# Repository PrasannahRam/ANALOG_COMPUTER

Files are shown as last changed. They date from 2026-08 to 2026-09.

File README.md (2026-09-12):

# ±15V Regulated Power Supply — Design Documentation

Part of the analog computer project (adder, subtractor, multiplier, integrator, differentiator built around NE5532D op-amps). This document covers the power supply subsystem: design goals, component selection, calculations, and simulation results.

## 1. Purpose

Provide a stable, low-noise ±15V DC supply to power the op-amp circuits and the CD4051 switching stage. Op-amps are sensitive to supply noise (it couples directly into the signal path), so filtering and regulation are prioritized alongside basic voltage accuracy.

## 2. Design Specifications

| Parameter | Value |
|---|---|
| Regulated output | +15V and −15V DC |
| Mains input | 230V RMS, 50Hz (Sri Lanka standard) |
| Regulator ICs | LM7815CT (positive), LM7915CT (negative) |
| Ripple target | As low as practical (achieved: sub-mV on final output, see §7) |

## 3. Circuit Architecture

```
Mains (230V, 50Hz)
      │
Center-tapped step-down transformer (230V primary : 15V-0-15V secondary)
      │
Full-wave rectifier (4× 1N4007, dual-rail configuration)
      │  (+ snubber caps across each diode)
Main filter capacitors (C1, C2 — bulk smoothing)
      │
Linear regulators (LM7815CT / LM7915CT)
      │  (+ input stability caps, output smoothing + HF caps)
Regulated ±15V output → op-amp circuit boards
```

The transformer's center tap is the single system ground reference (star ground) that all other grounds in the analog computer tie back to.

## 4. Component List (Bill of Materials)

| Ref. Des. | Component | Value / Part | Qty | Purpose |
|---|---|---|---|---|
| T1 | Center-tapped step-down transformer | 230V : 15V-0-15V | 1 | Steps mains down to a safe, rectifiable secondary voltage |
| D1–D4 | Rectifier diode | 1N4007 (1A, 1000V) | 4 | Full-wave rectification of both secondary halves into + and − rails |
| CSNUB1–CSNUB4 | Ceramic capacitor | 100nF | 4 | Suppress diode switching (reverse-recovery) noise |
| C1, C2 | Electrolytic capacitor | 2200µF, ≥35V | 2 | Main bulk ripple filtering after rectification |
| C3, C4 | Ceramic capacitor | 330nF | 2 | Regulator input stability (per datasheet) |
| U1 | Negative voltage regulator | LM7915CT | 1 | Regulates negative rail to −15V |
| U2 | Positive voltage regulator | LM7815CT | 1 | Regulates positive rail to +15V |
| C5, C6 | Electrolytic capacitor | 100µF | 2 | Regulator output bulk smoothing, transient response |
| C7, C8 | Ceramic capacitor | 100nF | 2 | High-frequency noise cleanup on regulated output |
| RL1, RL2 | Load resistor (simulation only) | 300Ω | 2 | Represents op-amp board current draw during simulation — not a real PCB part |
| F1 | Fuse (mains side) | Size per transformer VA rating | 1 | Safety — not simulated, required for physical build |

## 5. Principal Calculations

### 5.1 Transformer secondary voltage / turns ratio

The LM7815/LM7915 regulators need a minimum input voltage roughly 2–2.5V above their 15V output (dropout voltage), with a recommended practical minimum of about **17.5V** to regulate reliably.

Target secondary: **15V RMS per half** (30V RMS across the full secondary winding, tip to tip, since Multisim's turns-ratio field refers to the whole winding, not one half of a center-tapped winding).

```
Turns ratio = V_primary / V_secondary_full
            = 230V / 30V
            ≈ 7.65
```

This matches the corrected ratio used in simulation (previously set to ~15.3, which halved the intended per-side voltage — corrected to ~7.65 to get 15V RMS per half, confirmed in simulation).

### 5.2 Peak and rectified voltage

```
V_peak (per secondary half) = V_rms × √2
                             = 15V × 1.414
                             ≈ 21.2V

V_rectified ≈ V_peak − V_diode_drop
            ≈ 21.2V − 0.9V (typical 1N4007 forward drop)
            ≈ 20.3V
```

### 5.3 Ripple voltage across main filter caps (C1, C2)

```
V_ripple = I_load / (f_ripple × C)
```

Using an example load of 100mA per rail (**replace with your actual measured/estimated total op-amp + CD4051 current draw**) and C = 2200µF, with ripple frequency 100Hz (double the 50Hz mains, since full-wave rectification):

```
V_ripple = 0.1A / (100Hz × 2200µF)
         = 0.1 / 0.22
         ≈ 0.45V peak-to-peak
```

### 5.4 Regulator headroom check

```
Minimum voltage at ripple valley ≈ V_rectified − V_ripple
                                  ≈ 20.3V − 0.45V
                                  ≈ 19.85V
```

This sits comfortably above the ~17.5V minimum input requirement, giving roughly **2.3V of margin** even at the lowest point of the ripple waveform — this margin is what actually determines real-world stability under load, more so than the average/nominal voltage.

### 5.5 Regulator power dissipation (heatsinking check)

```
P_dissipated = (V_in_avg − V_out) × I_out
             = (20V − 15V) × 0.1A
             = 0.5W
```

At this dissipation level, the LM7815CT/LM7915CT can run without a heatsink, though adding a small clip-on heatsink is inexpensive insurance if the actual current draw ends up higher than the 100mA example used here.

**Note:** All calculations above use an assumed 100mA per rail as a placeholder. Recalculate §5.3–5.5 with your actual total current draw (sum of all NE5532D op-amp supply currents + CD4051 quiescent current) once known, for accurate final numbers.

## 6. Capacitor Placement Reasoning

| Capacitor(s) | Role | Why it's needed |
|---|---|---|
| CSNUB1–4 | Diode snubbers | Absorb reverse-recovery switching spikes from the rectifier diodes at the source, before they propagate as noise |
| C1, C2 | Bulk filtering | Smooth the pulsating rectifier output into near-steady DC before the regulator |
| C3, C4 | Regulator input stability | Prevent the regulator's internal feedback loop from oscillating due to trace/wire inductance |
| C5, C6 | Output bulk smoothing | Handle sudden current demand (e.g. op-amp transients) and mop up residual ripple |
| C7, C8 | Output HF cleanup | Ceramic caps handle high-frequency noise that electrolytics can't filter well, right before the rail reaches the op-amps |

**Overall pattern:** large electrolytics handle bulk/low-frequency smoothing, small ceramics handle high-frequency cleanup and stability, and snubber caps address noise at its source rather than filtering it out afterward.

## 7. Simulation Results (Multisim)

| Node | DC Value | Ripple (p-p) | Ripple Frequency |
|---|---|---|---|
| +15V rail (PR1, regulator output) | +14.9V | 198µV | 100Hz |
| −15V rail (PR2, regulator output) | −14.9V | 1.01mV | 100Hz |
| Secondary winding (PR3, pre-rectification) | — | 41.6V (raw AC) | 50Hz |

The 14.9V vs. 15.0V nominal is within the regulator's normal ±4% tolerance and is not a design issue. The sub-millivolt ripple on both regulated rails confirms the filtering/regulation stage is working as intended — well below what's needed for clean op-amp operation.

## 8. Build and Layout Recommendations

- **Star grounding:** all grounds (transformer center tap, regulator GND pins, op-amp board ground) should meet at a single point rather than daisy-chaining, to avoid ground loops.
- **Low-ESR electrolytics:** use low-ESR rated capacitors for C1, C2, C5, C6 where possible — they filter ripple more effectively and add less of their own high-frequency noise than generic electrolytics of the same value.
- **Physical placement:** keep all capacitors as close as possible to their respective pins (especially C3/C4 at the regulator input, and C7/C8 at the output) — lead/trace length reintroduces the inductance these capacitors are meant to cancel out.
- **Local decoupling at the op-amp boards:** in addition to this supply's own output capacitors, add local decoupling (e.g. ferrite bead + small ceramic/electrolytic pair) right where power enters each op-amp board, to guard against noise picked up along the wiring run.
- **Mains safety (not simulated):** include a fuse sized to the transformer's rated VA, and follow standard mains-wiring safety practice for the primary side.
- **Heatsinking:** add a small heatsink to U1/U2 if actual measured current draw pushes dissipation meaningfully above the ~0.5W estimate in §5.5.

## 9. Assumptions to Verify Before Finalizing PCB

- Actual total current draw of all op-amp stages + CD4051 switching stage (used to refine §5.3–5.5).
- Transformer VA/current rating sized with margin above that total.
- Confirm real 1N4007 forward voltage drop at your actual operating current (datasheet graph, not just the 0.7–0.9V typical figure used here).

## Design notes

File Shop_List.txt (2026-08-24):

RESISTORS — Metal Film

270 Ω       1%   0.25 W    ×3    (R1,R2,R3)
4.7 kΩ      1%   0.25 W    ×1    (R4)
3.3 kΩ      1%   0.25 W    ×1    (R5)
2.2 kΩ      1%   0.25 W    ×1    (R6)
2.2 kΩ      0.1% 0.25 W    ×4    (R7,R8,R9,R10)
50 Ω        1%   0.25 W    ×2    (R11,R12)
100 Ω       1%   0.25 W    ×1    (R13)
10 kΩ       1%   0.25 W    ×3    (R14,R16,R18)
1 kΩ        1%   0.25 W    ×2    (R15,R17)
1 MΩ        1%   0.25 W    ×1    (R20)

CAPACITORS

1 µF        ±5%  50 V+      ×5    (C1,C2,C3,C4,C5)
            Film preferred

OP-AMPS

NE5532                    ×3     (U1,U2,U3)

TRANSISTORS

2N3904                    ×10    (Q1–Q6 + spares)

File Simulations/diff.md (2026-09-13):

# Differentiator

### Triangular Input 
| frequency | C
| --- | --- |
1 - 10khz|100pF
10Hz - 1khz|10nF
5Hz - 10hz|100nF
1Hz - 5hz|1000nF

### Square Input
- Follow the above values.
- If unwanted spikes encountered increase the R2 value. 
- If the wave is distorted, reduce the R2 value.

---
---

# Component Justification for Active Differentiator Circuit

### 1. Active Element
* **Op-Amp (U1B - NE5532P):**
  * **Role:** Core high-speed, low-noise operational amplifier providing the required open-loop gain for differentiation.
  * **Value / Selection:** `NE5532P`
  * **Justification:** An ideal differentiator requires an op-amp with high bandwidth and slew rate to accurately process steep signal slopes ($\frac{dV}{dt}$) without slew-rate limiting or phase distortion. The NE5532 provides a high gain-bandwidth product ($10\text{ MHz}$), low noise voltage ($5\text{ nV}/\sqrt{\text{Hz}}$), and a slew rate of $9\text{ V}/\mu\text{s}$, making it suitable for processing signals up to $10\text{ kHz}$.

---

### 2. Switched Frequency-Band Capacitors ($C1, C2, C4, C5$)
* **Role:** Input differentiation capacitors determining the time constant $\tau = R_f C_{in}$ for each operating band.
* **Justifications:**
  * **$C1 = 1\ \mu\text{F}\ (1000\text{ nF})$ [$1\text{ Hz} - 5\text{ Hz}$]: At very low frequencies, the derivative ($\frac{dV}{dt}$) is tiny. A large capacitance ($1\ \mu\text{F}$) provides enough input current to yield a readable output voltage gain ($0.63\text{ V/V}$ to $3.14\text{ V/V}$) across $R1 = 100\text{ k}\Omega$.
  * **$C5 = 100\text{ nF}$ [$5\text{ Hz} - 10\text{ Hz}$]: Scaled down by $10\times$ relative to $C1$ to offset the higher input frequency range, keeping maximum band gain at $0.63\text{ V/V}$.
  * **$C4 = 10\text{ nF}$ [$10\text{ Hz} - 1\text{ kHz}$]: Covers two decades of frequency. A $10\text{ nF}$ value keeps the gain bounded between $0.063\text{ V/V}$ and $6.28\text{ V/V}$ at $1\text{ kHz}$, preventing op-amp output rail saturation.
  * **$C2 = 150\text{ pF}$ [$10\text{ kHz}$]: At high frequencies, $\frac{dV}{dt}$ is extremely large. Reducing $C_{in}$ to $150\text{ pF}$ maintains a gain near unity ($0.94\text{ V/V}$), preventing high-frequency noise amplification.

---

### 3. Stability & Input Resistance ($R2, R6$)
* **Role:** Input series limiting resistors.
* **Value / Selection:** $R2 = 10\text{ k}\Omega$, $R6 = 1\text{ k}\Omega$
* **Justification:** An ideal differentiator has zero input resistance, causing infinite high-frequency gain and unconditional instability (self-oscillation). Adding input series resistance caps the maximum high-frequency gain to $A_{max} = \frac{R1}{R_{in}}$ and forms a high-pass corner $f_c = \frac{1}{2\pi R_{in} C_{in}}$, stabilizing the feedback loop and dampening high-frequency noise.

---

### 4. Feedback Network ($R1, C6$)
* **Feedback Resistor ($R1 = 100\text{ k}\Omega$):**
  * **Role:** Sets the overall differentiation scaling factor ($V_{out} = -R1 \cdot C_{in} \cdot \frac{dV_{in}}{dt}$).
  * **Justification:** A high resistance ($100\text{ k}\Omega$) yields high transimpedance gain without requiring large, bulky input capacitors, keeping the load current within the NE5532 driving limit.
* **Feedback Capacitor ($C6 = 22\text{ pF}$):**
  * **Role:** High-frequency compensation capacitor (low-pass filter pole).
  * **Justification:** Placed in parallel with $R1$ to create a second-order pole at $f_p = \frac{1}{2\pi R1 C6} \approx 72.3\text{ kHz}$. This rolls off gain beyond the $10\text{ kHz}$ target bandwidth, suppressing high-frequency op-amp noise and ringing.

---

### 5. DC Compensation & Output Coupling ($R3, C3, R4$)
* **Bias Resistor ($R3 = 100\text{ k}\Omega$):**
  * **Role:** Non-inverting terminal DC bias balance.
  * **Justification:** Equalizes the DC source resistance seen by both inverting and non-inverting terminals ($R3 = R1 = 100\text{ k}\Omega$). This cancels out DC offset voltage shifts caused by the NE5532 input bias currents.
* **Output AC Coupling Capacitor ($C3 = 470\ \mu\text{F}$):**
  * **Role:** DC blocking capacitor at the output stage.
  * **Justification:** Prevents any residual op-amp DC offset voltage from reaching the measurement load/oscilloscope.
* **Output Load Resistor ($R4 = 100\text{ k}\Omega$):**
  * **Role:** Output ground reference and load resistor.
  * **Justification:** Combined with $C3$, it sets a high-pass corner frequency at $f_{HP} = \frac{1}{2\pi (470\mu\text{F})(100\text{k}\Omega)} \approx 0.003\text{ Hz}$. This ensures phase and amplitude linearity for input signals as low as $1\text{ Hz}$.

# Differentiator Transfer Function & Constant Derivation

### 1. General Transfer Function Derivation

For a practical active op-amp differentiator with input resistor $R_{in}$, input capacitor $C_{in}$, feedback resistor $R_f$, and parallel feedback capacitor $C_f$:

* **Input Impedance:** 
  $$Z_{in}(s) = R_{in} + \frac{1}{s C_{in}} = \frac{1 + s R_{in} C_{in}}{s C_{in}}$$

* **Feedback Impedance:** 
  $$Z_f(s) = R_f \parallel \frac{1}{s C_f} = \frac{R_f}{1 + s R_f C_f}$$

Using the inverting op-amp configuration gain formula $H(s) = -\frac{Z_f(s)}{Z_{in}(s)}$:

$$H_{diff}(s) = \frac{V_{out,stage}(s)}{V_{in}(s)} = - \left( \frac{s R_f C_{in}}{(1 + s R_{in} C_{in})(1 + s R_f C_f)} \right)$$

---

### 2. Time-Domain Differentiation Equation

In the operational differentiation sub-band ($f \ll \frac{1}{2\pi R_{in} C_{in}}$ and $f \ll \frac{1}{2\pi R_f C_f}$), the pole terms in the denominator evaluate to approximately $1$:

$$H_{diff}(s) \approx - s \cdot (R_f C_{in})$$

Taking the inverse Laplace transform gives the time-domain output equation:

$$v_{out}(t) = - K \cdot \frac{d v_{in}(t)}{dt}$$

Where the **differentiation scaling constant** $K$ is defined as:

$$K = R_f C_{in} \quad [\text{seconds}]$$

---

### 3. Frequency Band Specifications
* **Operating Range:** $0.003\text{ Hz}$ to $10\text{ kHz}$
* **Lower Cutoff Frequency ($f_L$):** Determined by the output AC-coupling network ($C3, R4$)
  $$f_L = \frac{1}{2\pi R_4 C_3} = \frac{1}{2\pi (100\text{ k}\Omega)(470\ \mu\text{F})} = \frac{1}{295.31} \approx 0.00339\text{ Hz} \approx 0.003\text{ Hz}$$
* **Upper Cutoff Frequency ($f_H$):** Determined by the feedback compensation network ($R1, C6$)
  $$f_H = \frac{1}{2\pi R1 C6} = \frac{1}{2\pi (100\text{ k}\Omega)(150\text{ pF})} = \frac{1}{9.425 \times 10^{-5}} \approx 10.61\text{ kHz} \approx 10\text{ kHz}$$

---

### 4. Output Filtering Stage ($C3, R4$)

The AC coupling network formed by $C3$ and $R4$ forms a high-pass filter:

$$H_{out}(s) = \frac{R_4}{R_4 + \frac{1}{s C_3}} = \frac{s R_4 C_3}{1 + s R_4 C_3} = \frac{1}{1 + \frac{1}{s R_4 C_3}}$$

Evaluating magnitude in the frequency domain ($s = j2\pi f$):

$$|H_{out}(f)| = \frac{1}{\sqrt{1 + \left( \frac{1}{2\pi f C_3 R_4} \right)^2}}$$

For operating frequencies within the passband ($f \ge 0.003\text{ Hz}$):

$$\frac{1}{2\pi f C_3 R_4} \ll 1 \implies H_{out}(s) \approx 1$$

---

### 5. Total System Transfer Function

Combining both the differentiator stage and the output filtering stage:

$$H_{total}(s) = H_{diff}(s) \cdot H_{out}(s) = - \left( \frac{s R_f C_{in}}{(1 + s R_{in} C_{in})(1 + s R_f C_f)} \right) \cdot \left( \frac{s R_4 C_3}{1 + s R_4 C_3} \right)$$

Within the operating passband ($0.003\text{ Hz} \le f \le 10\text{ kHz}$), all filter dynamics simplify:

$$H_{total}(s) \approx - s \cdot (R_f C_{in})$$

---

### 6. Switch-Wise Scaling Factor Calculations ($R_f = R1 = 100\text{ k}\Omega$)

| Switch Position | Selected Band | Active Capacitor ($C_{in}$) | Calculation ($K = R_f C_{in}$) | Value of $K$ |
| :--- | :--- | :--- | :--- | :--- |
| **Switch 4** | **1 Hz – 5 Hz** | $C1 = 1\ \mu\text{F}$ | $100\text{ k}\Omega \times 1\ \mu\text{F} = 10^5 \times 10^{-6}$ | $0.1\text{ s}\ (100\text{ ms})$ |
| **Switch 3** | **5 Hz – 10 Hz** | $C5 = 100\text{ nF}$ | $100\text{ k}\Omega \times 100\text{ nF} = 10^5 \times 10^{-7}$ | $0.01\text{ s}\ (10\text{ ms})$ |
| **Switch 2** | **10 Hz – 1 kHz** | $C4 = 10\text{ nF}$ | $100\text{ k}\Omega \times 10\text{ nF} = 10^5 \times 10^{-8}$ | $0.001\text{ s}\ (1\text{ ms})$ |
| **Switch 1** | **1 kHz – 10 kHz** | $C2 = 1\text{ nF}$ | $100\text{ k}\Omega \times 1\text{ nF} = 10^5 \times 10^{-9}$ | $0.0001\text{ s}\ (100\ \mu\text{s} / 0.1\text{ ms})$ |

---

### 7. Resulting Output Equations for Each Mode

* **Band 1 (1 Hz – 5 Hz, Switch 4 ON):**
  $$v_{out}(t) = -0.1 \cdot \frac{d v_{in}(t)}{dt}$$

* **Band 2 (5 Hz – 10 Hz, Switch 3 ON):**
  $$v_{out}(t) = -0.01 \cdot \frac{d v_{in}(t)}{dt}$$

* **Band 3 (10 Hz – 1 kHz, Switch 2 ON):**
  $$v_{out}(t) = -0.001 \cdot \frac{d v_{in}(t)}{dt}$$

* **Band 4 (1 kHz – 10 kHz, Switch 1 ON):**
  $$v_{out}(t) = -0.0001 \cdot \frac{d v_{in}(t)}{dt}$$

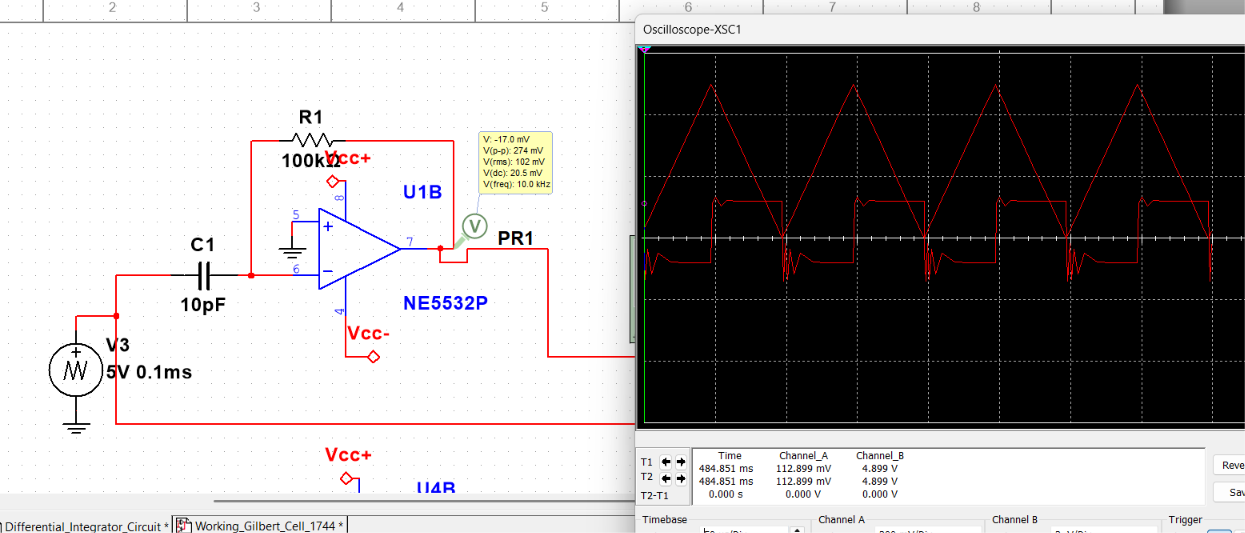
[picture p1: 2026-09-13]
ScreenShots/differentiator_1.png

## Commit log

2026-09-05 Integrator circuit implemented
2026-09-09 updated diff circuit
2026-09-09 Updated feedback capacitor
2026-09-10 Finalized Multiplier Circuit
    Use Multisim Software
2026-09-12 Create README for ±15V Regulated Power Supply
    Added detailed design documentation for ±15V regulated power supply, including specifications, calculations, and simulation results.
2026-09-12 Power Supply Final Simulation
2026-09-12 Add design documentation for analog multiplier
    Added detailed design documentation for the analog multiplier subsystem, including purpose, circuit architecture, component list, principal calculations, and verification methods.
2026-09-12 Center tapped Voltage Step down converter
    15 0 15
    Use this to design the PCB
    And LM7815CT and LM7915CT Has similar foot print use this model for both
